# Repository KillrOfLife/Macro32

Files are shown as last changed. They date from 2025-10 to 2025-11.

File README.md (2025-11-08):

# Macro32

The Macro32 is a macropad featuring a stm32.
This project was a way for me to learn how to integrate an IC of my choosing on my PCB.
It was also my fist project using kicad

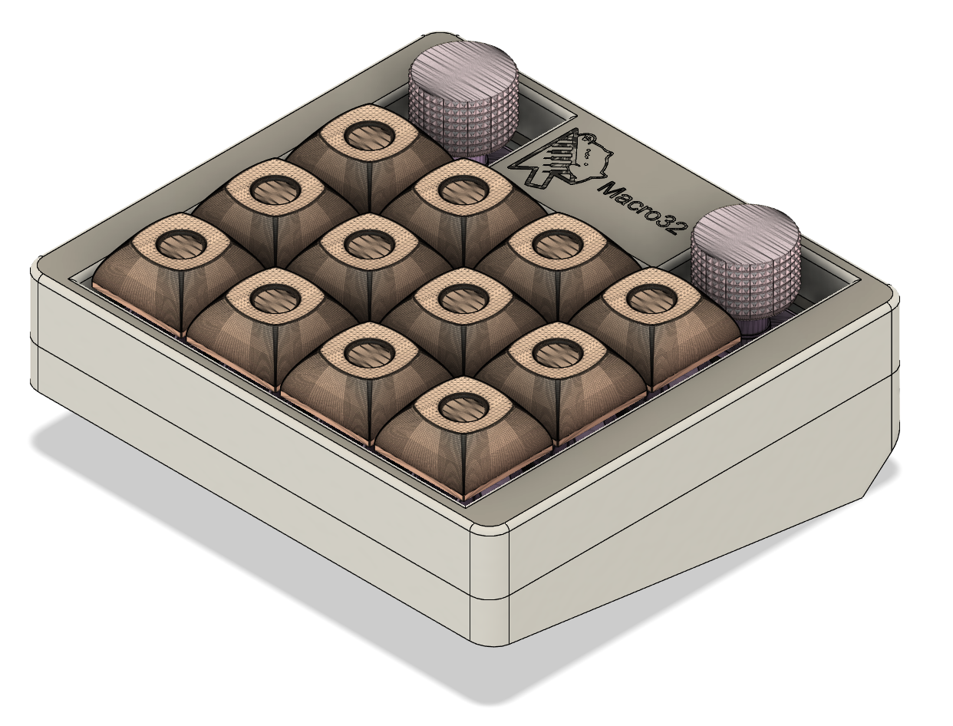
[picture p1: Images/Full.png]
Image of the macropad


## Take a look

[kicad project](https://kicanvas.org/?github=https://github.com/KillrOfLife/Macro32/blob/main/PCB/macro32.kicad_pro)

## How can I make it myself

Great question!
Go look in the github releases for the latest tag
There you should find the downloads for the PCB production files (aka gerbers)
And the STL's for the case parts if you want that too. (you may need to download the source code)

## How to assemble

For any help assembling this macropad refer to the [build guide](https://github.com/KillrOfLife/Macro32/blob/main/buildguide.md).

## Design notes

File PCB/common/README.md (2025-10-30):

# Common

A collection of footprints, symbols, and 3D models for building mechanical keyboards with Kicad.

This is my own common library consisting of that of Scottokeebs kbd, and some custom made.

# Installation

1. Add a `COMMON` path to match where the `Common` folder is located.

   !todo replace SCOTTOKEEBS_KICAD with COMMON

   Preferences -> Configure Paths
   Configure Paths

2. Add the symbol library.
   Preferences -> Manage Symbol Libraries
   Symbol Libraries

3. Add the footprint libraries.
   Preferences -> Manage Footprint Libraries
   Footprint Libraries      

4. Ensure hotkeys match tutorial.
   Settings
   Import hotkeys
   CleanShot 2025-06-30 at 11 00 42@2x
   
5. Match Scotto Configuration (Optional).
   Settings
   Reveal
   Preferences
   Theme

6. That's it, you should now have everything you need!

# Common grid sizes

-   18x17mm (Choc)
    -   1.00u - X: 18, Y:17
    -   0.50u - X: 9, Y: 8.5
    -   0.25u - X: 4.5, Y: 4.25
-   19.05x19.05 (MX/Alps)
    -   1.00u - X: 19.05, Y: 19.05
    -   0.50u - X: 9.525, Y: 9.525
    -   0.25u X: 4.7625, Y: 4.7625

# Common Shortcuts

-   **Add (A)** - Add a footprint or symbol.
-   **Set Origin Point (S)** - Set where everything else will move in relation to.
-   **Move with Reference (])** - Move a footprint with a reference point.
-   **Track Tool (X)** - Place traces
-   **Add Via (V)** - Place a via to run a trace between PCB layers.
-   **Flip (F)** - Switch footprint between back and front of the PCB.

# Resources

Please refer to each library in order to understand the license it uses, most are Creative Commons CC-BY-SA 4.0.

-   [Keyswitch Library](https://github.com/kiswitch/kiswitch/tree/main) - 3D models and footprints for switches, stabilizers, and sockets.
-   [Raspberry Pi Pico](https://github.com/ncarandini/KiCad-RP-Pico) - 3D model, footprint, and symbol.
-   [Arduino Pro Micro](https://github.com/g200kg/kicad-lib-arduino) - Footprint and symbol.
-   [Marbastlib](https://github.com/ebastler/marbastlib) - Symbols.
-   [Kleeb](https://github.com/crides/kleeb) - 3D models, symbols, and footprints.
-   [Keebio](https://github.com/keebio/Keebio-Parts.pretty) - 3D models, footprints, and symbols.
-   [Adafruit](https://github.com/adafruit/Adafruit_CAD_Parts/tree/main?tab=MIT-1-ov-file#readme) - 3D models

# Credits

Feel free to reach out to me on Discord if you want to help get a component into the library.

-   nice!nano - Base dimensions and placement by @Knotherface, can be found on GitHub as [Leopere](https://github.com/Leopere).

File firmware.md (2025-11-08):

# Firmware

Congrats, you made it this far!

Time to give the project some life.

## Compile the firmware yourself

### set up the build environment

follow the official guide cause i'm too lazy
[build environment official docs](https://get.vial.today/docs/porting-to-vial.html#1-prepare-your-build-environment)

### Add the keyboard to the build environment

copy the contents of [Code](https://github.com/KillrOfLife/Macro32/tree/main/Code) to the keyboards folder in qmk-vial

### Compile the firmware

Use the following command for vial compatibility

```sh
qmk compile -kb killroflife/macro32_v1 -km vial
```

Use the following command if you want to suffer with QMK

```sh
qmk compile -kb killroflife/macro32_v1 -km default
```

## Flash the firmware

1. Connect the keyboard to your computer
2. hold the boot button, press and release the reset button and lastly release the boot button
    This made sure the board is in DFU or flashing mode
3. use qmk toolbox to flash the firmware file

## Customize the board

If you've chosen the sane option to use vial go to [vial.rocks](https://vial.rocks/) connnect your board and you'll be able to choose the actions when you press a key.

If you've chosen QMK, GOOD LUCK you've brought this on yourself.

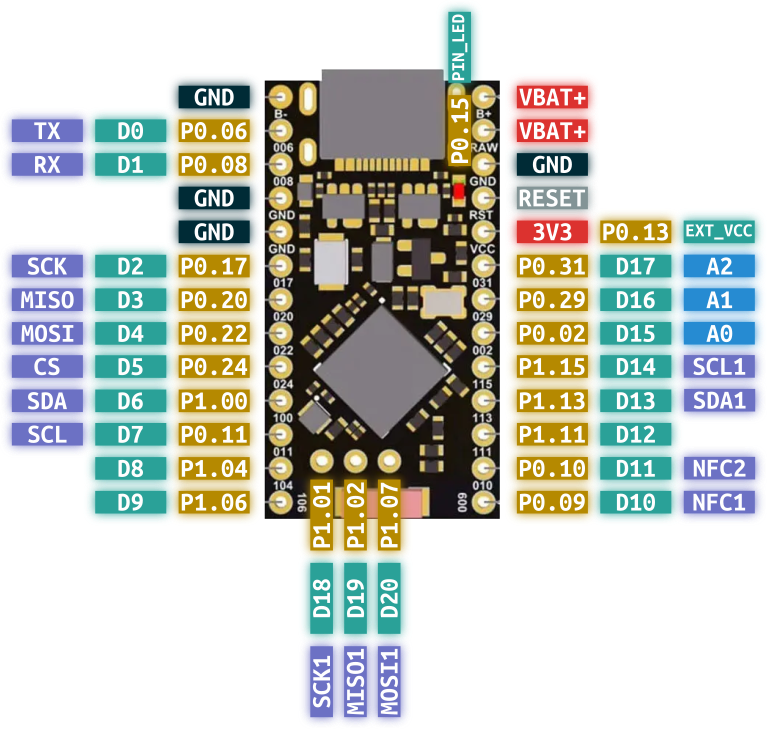
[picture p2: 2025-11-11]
supermini_nrf52840.png

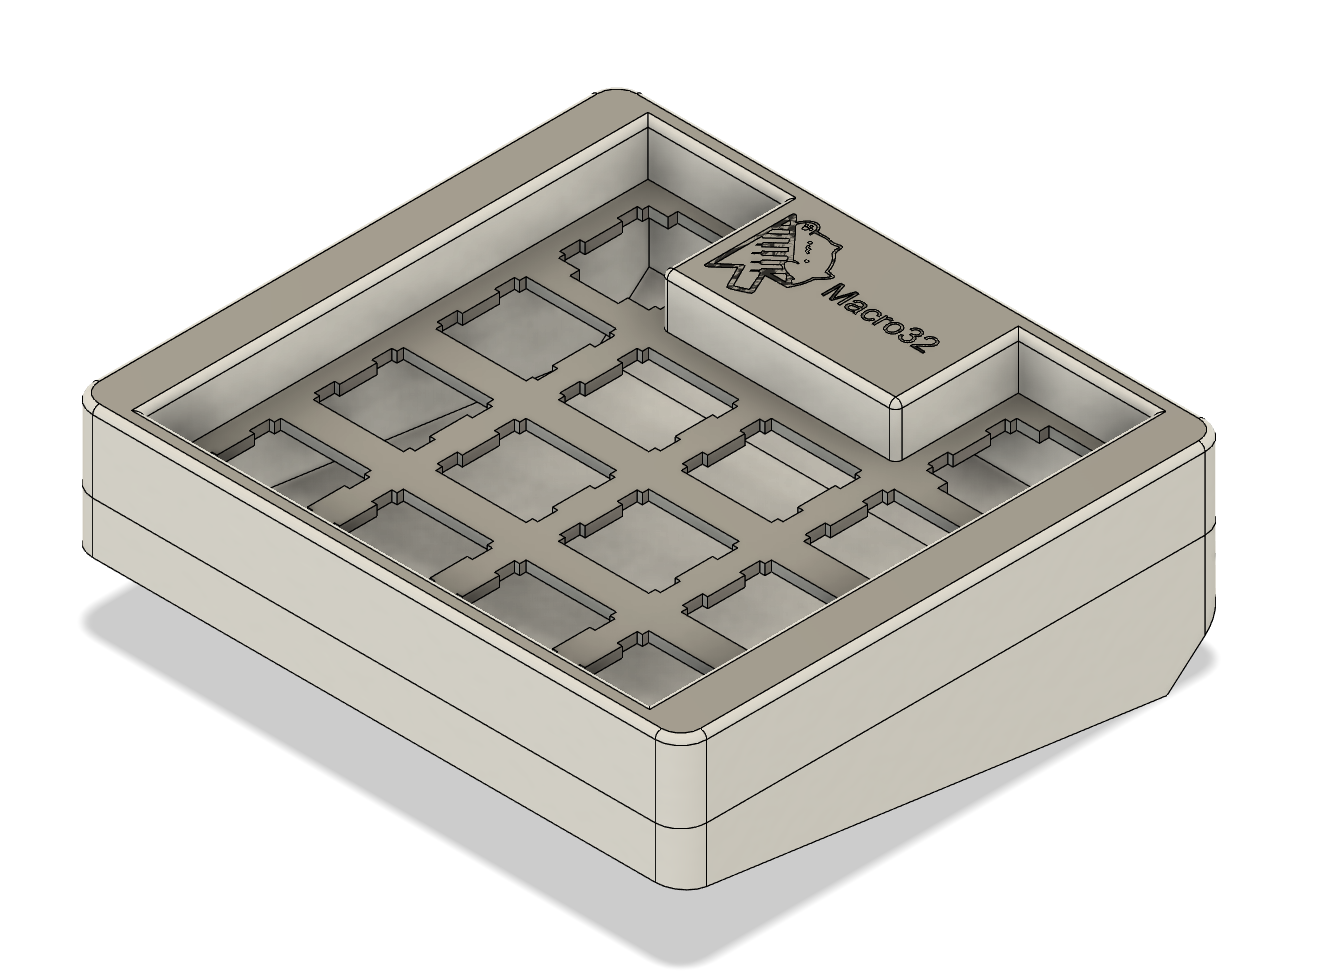
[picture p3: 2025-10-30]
Images/Case.png

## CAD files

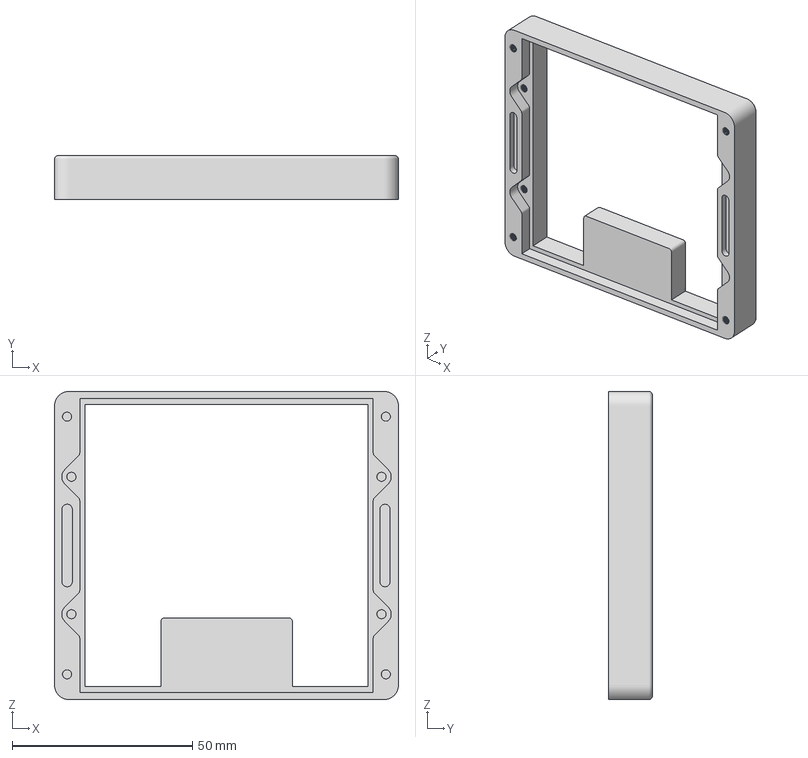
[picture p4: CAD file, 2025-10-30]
Model/Top.3mf
95.3 x 12.2 x 85.4 mm
Top

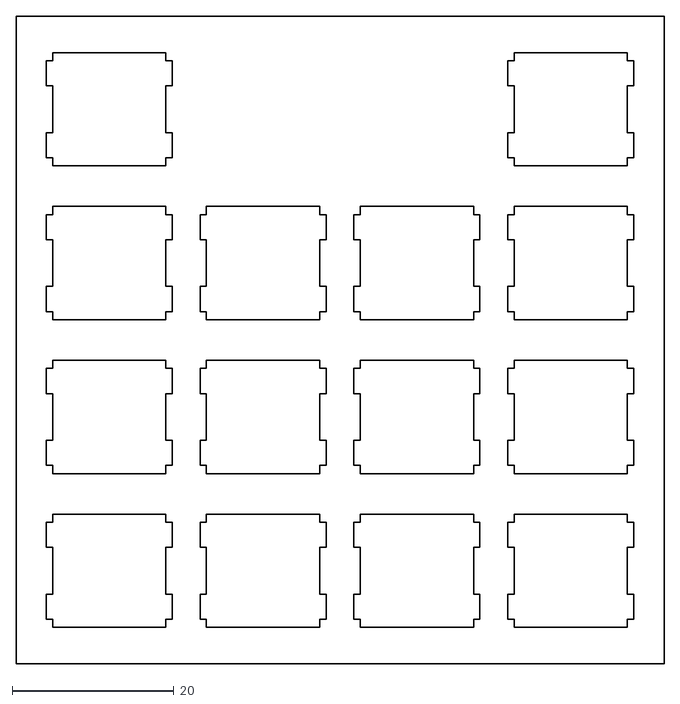
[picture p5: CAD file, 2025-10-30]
PCB/switch plate.dxf
80.2 x 80.2

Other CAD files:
Model/Bottom.3mf
Model/Plate.3mf

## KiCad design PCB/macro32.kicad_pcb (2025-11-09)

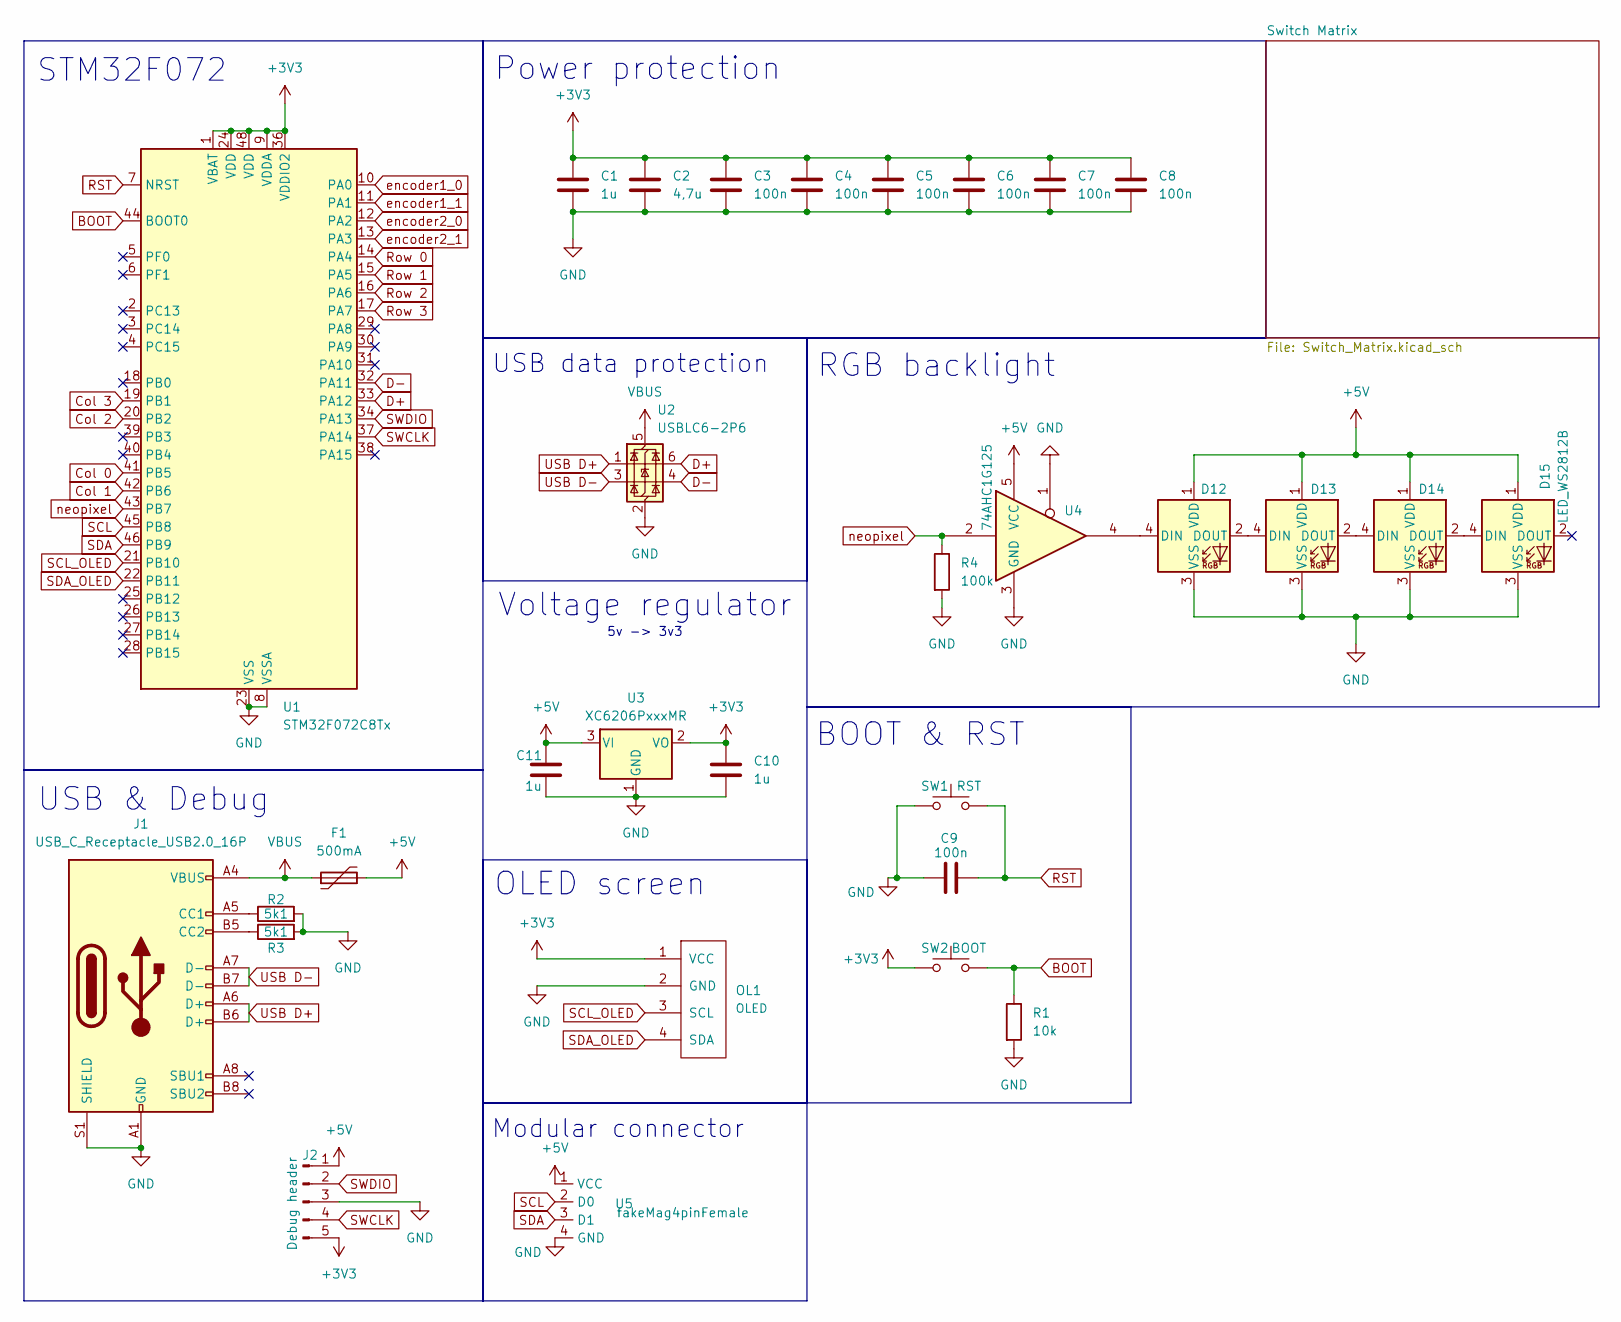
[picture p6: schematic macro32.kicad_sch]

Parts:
C1, C10, C11: 1u; LED_0805
C2: 4,7u; LED_0805
C3, C4, C5, C6, C7, C8, C9: 100n; LED_0805
D12, D13, D14, D15: LED_WS2812B
F1: 500mA; Resistor_1206
J1: USB_C_Receptacle_USB2.0_16P; USB_C_Receptacle_GCT_USB4110
J2: Debug header; PinHeader_1x05_P2.54mm_Vertical
OL1: OLED; OLED_128x64
R1: 10k; Resistor_0805
R2, R3: 5k1; Resistor_0805
R4: 100k; Resistor_0805
SW1: RST; SW_SPST_TS-1088-xR020
SW2: BOOT; SW_SPST_TS-1088-xR020
U1: STM32F072C8Tx; LQFP-48_7x7mm_P0.5mm
U2: USBLC6-2P6; SOT-666
U3: XC6206PxxxMR; SOT-23-3
U4: 74AHC1G125; SOT-353_SC-70-5_Handsoldering
U5: fakeMag4pinFemale; fakemag4pin90degFemale

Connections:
+3V3: C1.1, C2.1, C3.1, C4.1, C5.1, C6.1, C7.1, C8.1, C10.1, J2.5, OL1.1 (VCC), SW2.1, U1.1 (VBAT), U1.9 (VDDA), U1.24 (VDD), U1.36 (VDDIO2), U1.48 (VDD), U3.2 (VO)
+5V: C11.1, D12.1 (VDD), D13.1 (VDD), D14.1 (VDD), D15.1 (VDD), F1.2, J2.1, U3.3 (VI), U4.5 (VCC), U5.1 (VCC)
BOOT: R1.1, SW2.2, U1.44 (BOOT0)
Col 0: U1.41 (PB5); also elsewhere on the board
Col 1: U1.42 (PB6); also elsewhere on the board
Col 2: U1.20 (PB2); also elsewhere on the board
Col 3: U1.19 (PB1); also elsewhere on the board
D+: U1.33 (PA12), U2.6 (I/O1)
D-: U1.32 (PA11), U2.4 (I/O2)
GND: C1.2, C2.2, C3.2, C4.2, C5.2, C6.2, C7.2, C8.2, C9.1, C10.2, C11.2, D12.3 (VSS), D13.3 (VSS), D14.3 (VSS), D15.3 (VSS), J1.A1 (GND), J1.A12 (GND), J1.B1 (GND), J1.B12 (GND), J1.S1 (SHIELD), J2.3, OL1.2 (GND), R1.2, R2.2, R3.2, R4.2, SW1.1, U1.8 (VSSA), U1.23 (VSS), U1.35 (VSS), U1.47 (VSS), U2.2 (GND), U3.1 (GND), U4.1, U4.3 (GND), U5.4 (GND); also elsewhere on the board
unnamed: D12.4 (DIN), U4.4
unnamed: D12.2 (DOUT), D13.4 (DIN)
unnamed: D13.2 (DOUT), D14.4 (DIN)
unnamed: D14.2 (DOUT), D15.4 (DIN)
unnamed: J1.A5 (CC1), R2.1
unnamed: J1.B5 (CC2), R3.1
RST: C9.2, SW1.2, U1.7 (NRST)
Row 0: U1.14 (PA4); also elsewhere on the board
Row 1: U1.15 (PA5); also elsewhere on the board
Row 2: U1.16 (PA6); also elsewhere on the board
Row 3: U1.17 (PA7); also elsewhere on the board
SCL: U1.45 (PB8), U5.2 (D0)
SCL_OLED: OL1.3 (SCL), U1.21 (PB10)
SDA: U1.46 (PB9), U5.3 (D1)
SDA_OLED: OL1.4 (SDA), U1.22 (PB11)
SWCLK: J2.4, U1.37 (PA14)
SWDIO: J2.2, U1.34 (PA13)
USB D+: J1.A6 (D+), J1.B6 (D+), U2.1 (I/O1)
USB D-: J1.A7 (D-), J1.B7 (D-), U2.3 (I/O2)
VBUS: F1.1, J1.A4 (VBUS), J1.A9 (VBUS), J1.B4 (VBUS), J1.B9 (VBUS), U2.5 (VBUS)
encoder1_0: U1.10 (PA0); also elsewhere on the board
encoder1_1: U1.11 (PA1); also elsewhere on the board
encoder2_0: U1.12 (PA2); also elsewhere on the board
encoder2_1: U1.13 (PA3); also elsewhere on the board
neopixel: R4.1, U1.43 (PB7), U4.2

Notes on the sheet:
Power protection
STM32F072
5v -> 3v3
RGB backlight
USB & Debug
Modular connector
Voltage regulator
BOOT & RST
OLED screen
USB data protection

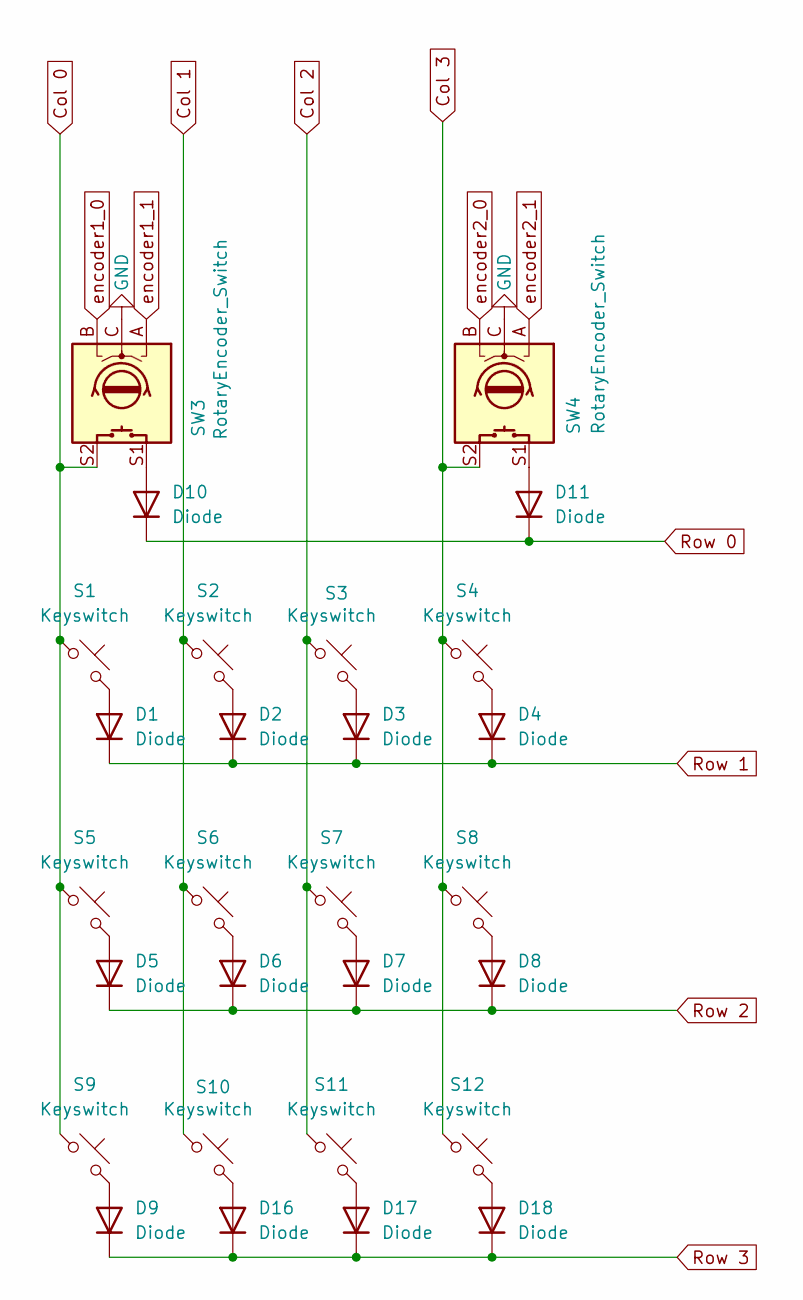
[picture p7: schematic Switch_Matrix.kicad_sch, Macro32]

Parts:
D1, D2, D3, D4, D5, D6, D7, D8, D9, D10, D11, D16, D17, D18: Diode; Diode_SOD-123
S1, S2, S3, S4, S5, S6, S7, S8, S9, S10, S11, S12: Keyswitch; Hotswap_MX_1.00u
SW3, SW4: RotaryEncoder_Switch; keyswitch_cherrymx_hotswap_1u_rotary_encoder_ec12

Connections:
Col 0: S1.1, S5.1, S9.1, SW3.S2; also elsewhere on the board
Col 1: S2.1, S6.1, S10.1; also elsewhere on the board
Col 2: S3.1, S7.1, S11.1; also elsewhere on the board
Col 3: S4.1, S8.1, S12.1, SW4.S2; also elsewhere on the board
GND: SW3.C, SW4.C; also elsewhere on the board
unnamed: D1.2 (A), S1.2
unnamed: D2.2 (A), S2.2
unnamed: D3.2 (A), S3.2
unnamed: D4.2 (A), S4.2
unnamed: D5.2 (A), S5.2
unnamed: D6.2 (A), S6.2
unnamed: D7.2 (A), S7.2
unnamed: D8.2 (A), S8.2
unnamed: D9.2 (A), S9.2
unnamed: D10.2 (A), SW3.S1
unnamed: D11.2 (A), SW4.S1
unnamed: D16.2 (A), S10.2
unnamed: D17.2 (A), S11.2
unnamed: D18.2 (A), S12.2
Row 0: D10.1 (K), D11.1 (K); also elsewhere on the board
Row 1: D1.1 (K), D2.1 (K), D3.1 (K), D4.1 (K); also elsewhere on the board
Row 2: D5.1 (K), D6.1 (K), D7.1 (K), D8.1 (K); also elsewhere on the board
Row 3: D9.1 (K), D16.1 (K), D17.1 (K), D18.1 (K); also elsewhere on the board
encoder1_0: SW3.B; also elsewhere on the board
encoder1_1: SW3.A; also elsewhere on the board
encoder2_0: SW4.B; also elsewhere on the board
encoder2_1: SW4.A; also elsewhere on the board

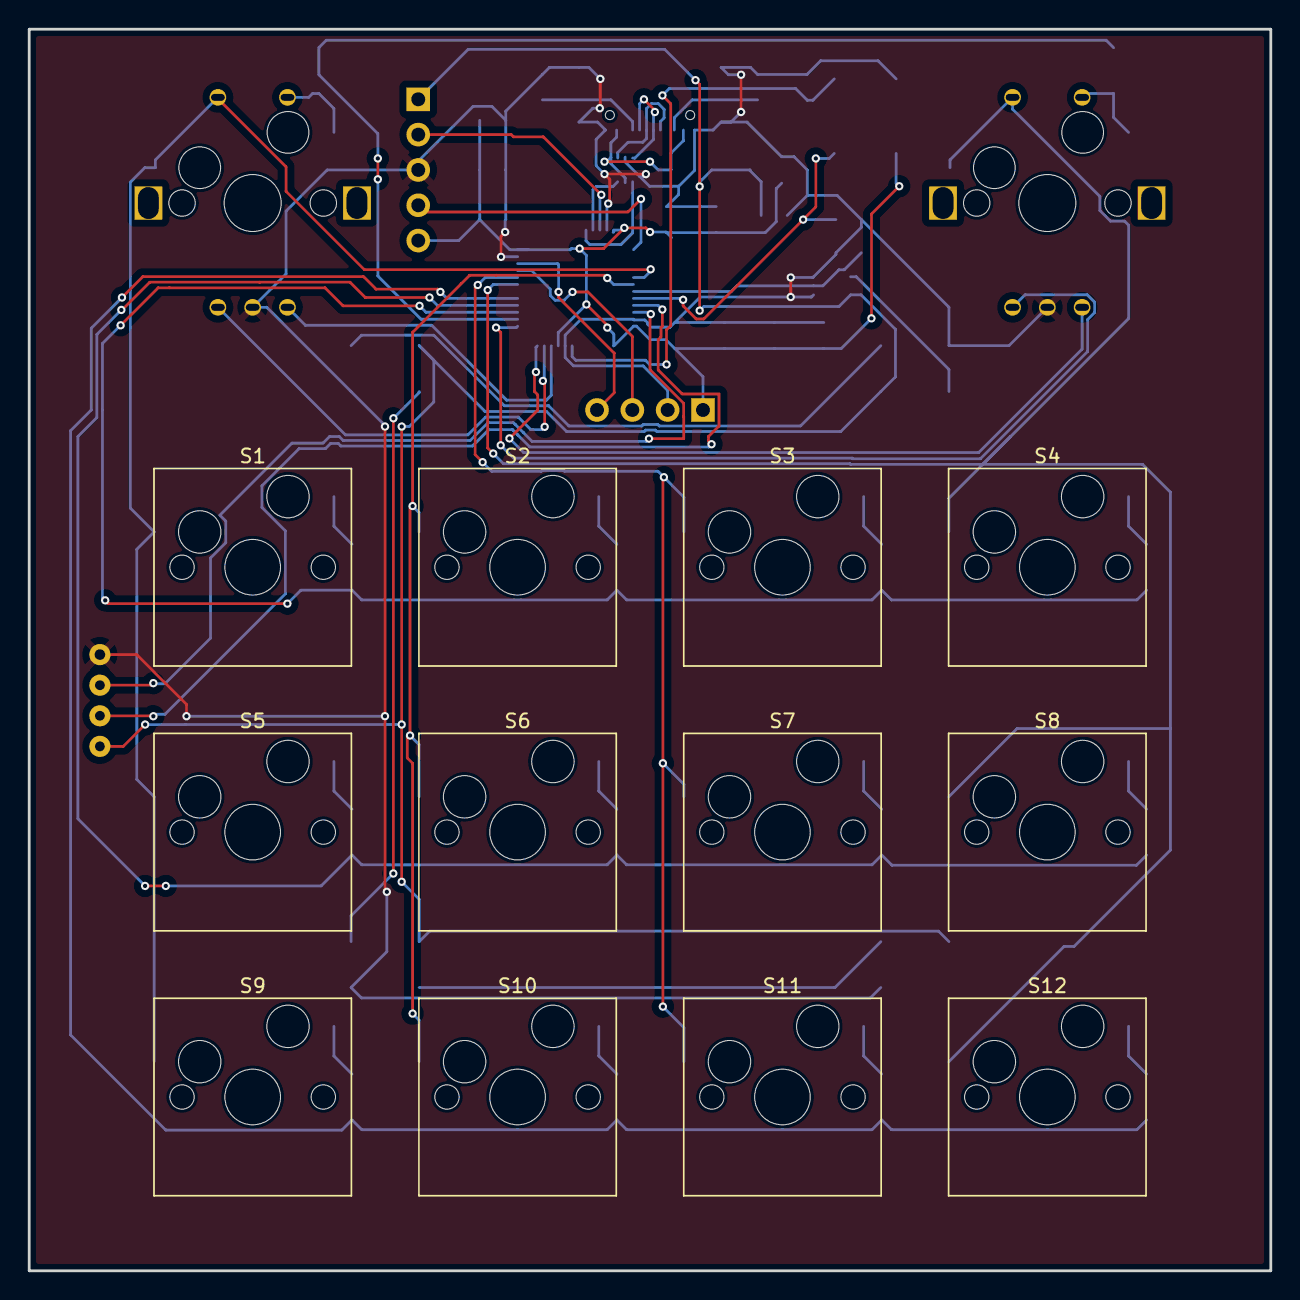
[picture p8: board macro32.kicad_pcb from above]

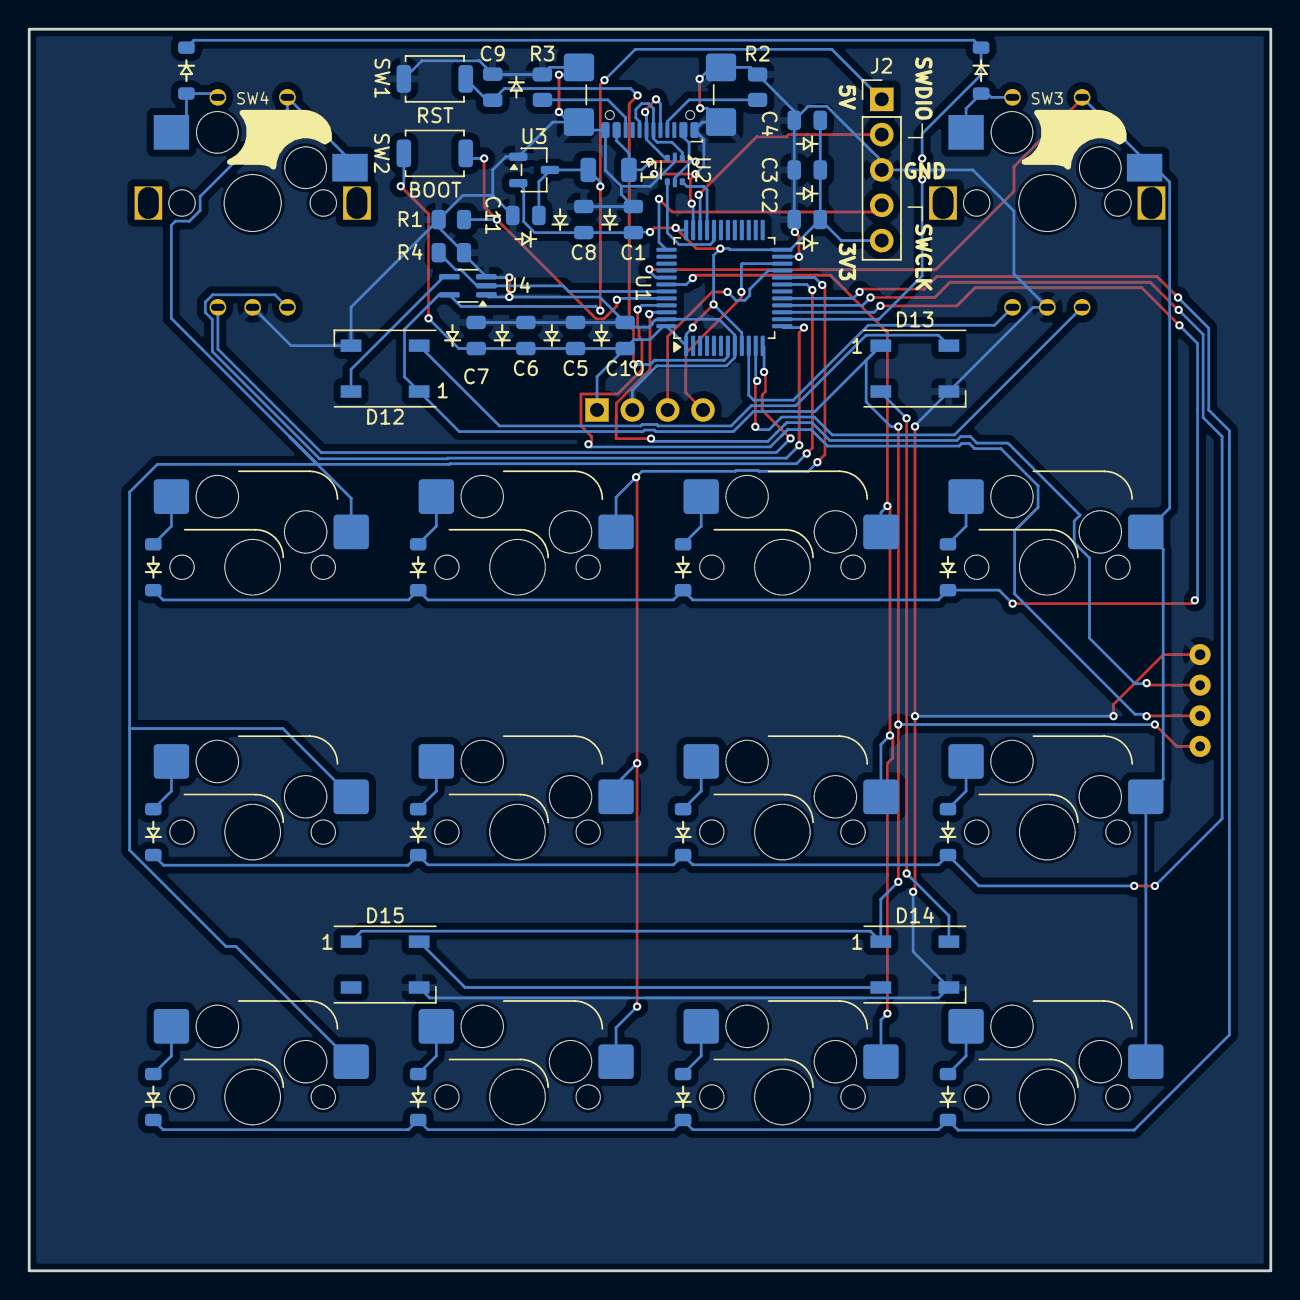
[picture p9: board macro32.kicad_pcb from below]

Board: 2 copper layers, 89.3 x 89.3 mm, 58 parts (45 on the bottom side), 49 nets.

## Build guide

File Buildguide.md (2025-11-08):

# Build Guide

This is the build guide for the Macro32

Image of the macropad

## Parts

### PCB components - Required

| Name | Count | Remarks |
|:---|:---|:---|
| Ceramic capacitor 4.7uF | 1 | 4.7uF with 0805 footprint |
| Ceramic capacitor 1uF | 3 | 1uF with 0805 footprint |
| Ceramic capacitor 100nF | 7 | 100nF with 0805 footprint |
| Diode SOD-123 | 14 | |
| Fuse 500mA | 1 | Optional but reccomended |
| USB-C port | 1 | USB4110 |
| Resistor 10k | 1 | 0805 footprint |
| Resistor 5.1k | 2 | 0805 footprint |
| MX hotswap socket | 12 - 14  | depending if you want rotary encoders |
| tiny switch | 2 | SW_SPST_TS-1088-xR020 |
| STM32F072 | 1 | LQFP48 format |
| voltage regulator | 1 | XC6206PxxxMR SOT-23-3 footprint |
| --------------------------- | -------- | ------------------------------------  |
| ec12 rotary encoder | 0 - 2 | |
| LED | 4 | WS2812B for underglow |
| LED Line driver | 1 | 74AHC1G125 SOT-353 footprint |
| Resistor 100k | 1 | 0805 footprint (for LED) |

### Special case

!!!! ONLY IN V1
Due to a mistake in the shematic the USB ESD protector was inproperly connected.
This means the USB ESD protection is not needed in V1.

| Name | Count | Remarks |
|:---|:---|:---|
| USB ESD protection | 1 | USBLC6-2P6 SOT-666 footprint |

### Full build components

| Name | Count | Remarks |
|:---|:---|:---|
| PCB | 1 | |
| Case | 1 | Top and bottom |
| Switch plate | 1 | FR4 1.6mm thick or 3d printed |
| Key switches | 12 - 14 | Only Cherry MX compatible |
| Keycaps | 12 - 14 | 1u |
| Screw M3x8 | 8 | For Case assembly |
| Type-C cable | 1 | |
| ----------------------- | --------------- | --------------------------- |
| Rotary Encoder knobs | 0 - 2 pieces | |

## Firmware preparation

Please see [firmware.md](./firmware.md).

## Build

I'll be starting the guide from an unpopulated PCB
If you let jlcpcb or similar populate the PCB for you then skip to part !TODO
<!-- TODO -->

### 1. Make sure you have all the components to populate the PCB

Components can be found in the [BOM](https://raw.githubusercontent.com/KillrOfLife/Macro32/refs/heads/main/PCB/production/bom.csv) or above in the components list.

You can make the choice between having 14 switches and no rotary encoders or 12 switches with rotary encoders.
The rotary encoders are wired as such that you can place encoders with a built in switch.

!!!! ONLY IN V1
Due to a mistake in the shematic the USB ESD protector was inproperly connected.
This means the USB ESD protection is not needed in V1.

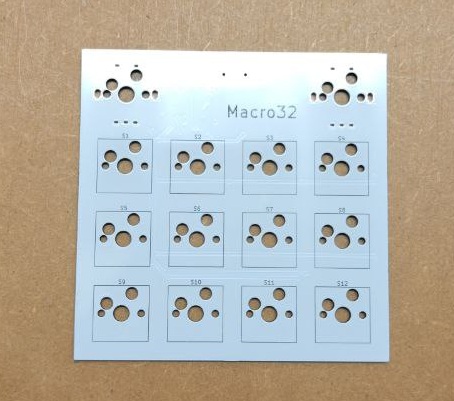
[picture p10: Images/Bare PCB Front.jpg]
bare PCB front

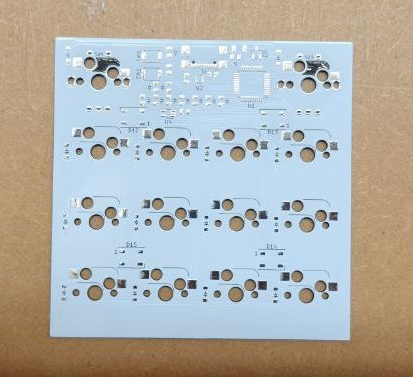
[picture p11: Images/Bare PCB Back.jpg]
bare PCB back


### 2. Place Components

1. In case you have a stencil, use it with some solder paste to apply solder paste on the pads of the bottom of the PCB.
This makes assembly easier than soldering all the small components by hand.

2. Place the components on the board
I recommend placing small components, the USB-C header and the microcontroller in this step
3. use a heat gun or heatplate to melt the solder.
4. Place your Cherry MX hostwap sockets on the board and give them a little touch with your soldering iron.
5. now you can insert your rotary encoders on the FRONT SIDE OF THE BOARD and solder the connectors on the back.
6. Your PCB should now look something like this

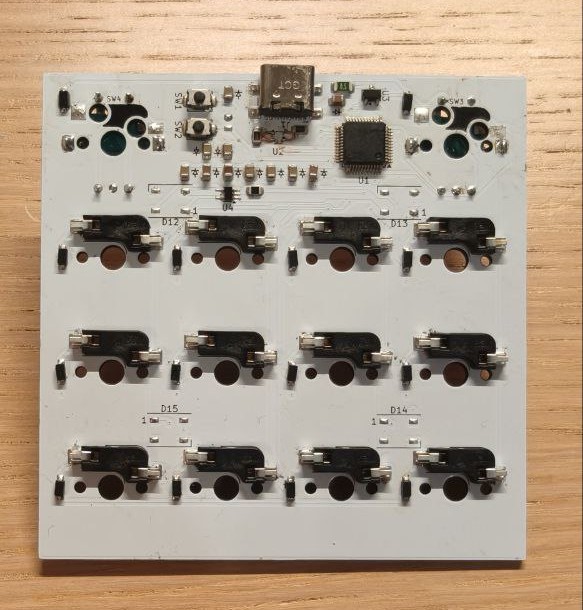
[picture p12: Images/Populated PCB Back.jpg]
Populated PCB back
    

    Theres one more step to go, manually fix my mistake and solder a few pads with some wire

7. connect the pads of U2 (the ESD protector) to make sure the USB data can pass to the microcontroller (follow the yellow to connect the pads)

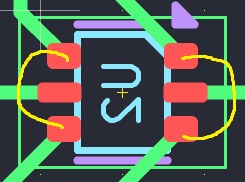
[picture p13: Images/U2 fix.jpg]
U2 fix
    

Your PCB should now be working!
go ahead and flash some firmware [firmware.md](./firmware.md).

### 3. Assemble
<!-- more images incoming for assembly process -->

1. Attach the switches to the switch plate.

2. Add the PCB to the bottom of the switches.

3. Screw the switch plate to the top of the chassis.

4. Add the bottom of the chassis.

5. Screw the bottom to the top of the chassis.

6. Optional add some rubber feet

7. Go ahead and jazz it up with some colorful keycaps.

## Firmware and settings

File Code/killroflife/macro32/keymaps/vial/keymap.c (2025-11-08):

#include QMK_KEYBOARD_H
#include "quantum.h"

const uint16_t PROGMEM keymaps[][MATRIX_ROWS][MATRIX_COLS] = {
	[0] = LAYOUT(
		KC_F13,                   KC_F14,
        KC_A, KC_F16 , KC_F17 , KC_F18,
        KC_F19, KC_F20 , KC_F21 , KC_F22,
        KC_F23, KC_F24 , KC_LEFT , KC_RIGHT
    ),
    [1] = LAYOUT(
		KC_F13,                   KC_F14,
        KC_S, KC_F16 , KC_F17 , KC_F18,
        KC_F19, KC_F20 , KC_F21 , KC_F22,
        KC_F23, KC_F24 , KC_LEFT , KC_RIGHT
    ),
    [2] = LAYOUT(
		KC_F13,                   KC_F14,
        KC_D, KC_F16 , KC_F17 , KC_F18,
        KC_F19, KC_F20 , KC_F21 , KC_F22,
        KC_F23, KC_F24 , KC_LEFT , KC_RIGHT
    ),
    [3] = LAYOUT(
		KC_F13,                   KC_F14,
        KC_F, KC_F16 , KC_F17 , KC_F18,
        KC_F19, KC_F20 , KC_F21 , KC_F22,
        KC_F23, KC_F24 , KC_LEFT , KC_RIGHT
    ),
};

#if defined(ENCODER_MAP_ENABLE)
const uint16_t PROGMEM encoder_map[][NUM_ENCODERS][NUM_DIRECTIONS] = {
    [0] = { ENCODER_CCW_CW(TO(3), TO(1)),  ENCODER_CCW_CW(KC_VOLD, KC_VOLU)  },
    [1] = { ENCODER_CCW_CW(TO(0), TO(2)),  ENCODER_CCW_CW(KC_VOLD, KC_VOLU)  },
    [2] = { ENCODER_CCW_CW(TO(1), TO(3)),  ENCODER_CCW_CW(KC_VOLD, KC_VOLU)  },
    [3] = { ENCODER_CCW_CW(TO(2), TO(0)),  ENCODER_CCW_CW(KC_VOLD, KC_VOLU)  },
    // [1] = { ENCODER_CCW_CW(UG_HUED, UG_HUEU),  ENCODER_CCW_CW(UG_SATD, UG_SATU)  },
    // [2] = { ENCODER_CCW_CW(UG_VALD, UG_VALU),  ENCODER_CCW_CW(UG_SPDD, UG_SPDU)  },
    // [3] = { ENCODER_CCW_CW(UG_PREV, UG_NEXT),  ENCODER_CCW_CW(KC_RIGHT, KC_LEFT) },
};
#endif

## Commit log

2025-11-08 Remove obsolete files and added them to .gitignore
    [bom.csv, designators.csv, positions.csv]
2025-11-08 Added OLED_SPI connector for the NICE!view
2025-11-08 Schema for V2 Did some cleanup and seperated the switch matrix to it's own file fixes #1
    [Switch_Matrix.kicad_sch, macro32.kicad_sch]
2025-11-09 Update OLED_128x64 footprint version and adjust properties
2025-11-09 Adjust PCB layout and added magnetic connector for modularity
    [Switch_Matrix.kicad_sch, macro32.kicad_sch]
2025-11-09 PCB for v2 in the works
    [macro32.kicad_pcb]
2025-11-09 PCB design v2
    [macro32.kicad_pcb]
2025-11-11 added kicad support for nrf52840
